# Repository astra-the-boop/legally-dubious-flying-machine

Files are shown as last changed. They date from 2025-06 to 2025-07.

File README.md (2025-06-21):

# la legally dubious flying machine
### Might break several aerospace, telecom, and public order laws but we ball
## Project members: Astra (@astra.celestine on Slack), Ghost (@Minh Anh Ghost on Slack), MD (not in hc), Doggy (not in hc), bingle

## Basically, an RC plane based around just regular commercial airplanes.; ~1m in length; Arduino-controlled; Using LoRa for communication; might add autopilot; DIY Controller + software

---
## Dependencies and libraries or whatever:
-

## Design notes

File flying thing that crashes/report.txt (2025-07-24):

Warning: Width correction constrained.  The width correction value must be in the range of [0.000001 mm; 0.199999 mm] for the current design rules.
Plotted to 'C:\Users\Ghost\Documents\GitHub\legally-dubious-flying-machine\flying thing that crashes\flying thing that crashes-F_Cu.gbr'.
Plotted to 'C:\Users\Ghost\Documents\GitHub\legally-dubious-flying-machine\flying thing that crashes\flying thing that crashes-B_Cu.gbr'.
Plotted to 'C:\Users\Ghost\Documents\GitHub\legally-dubious-flying-machine\flying thing that crashes\flying thing that crashes-F_Paste.gbr'.
Plotted to 'C:\Users\Ghost\Documents\GitHub\legally-dubious-flying-machine\flying thing that crashes\flying thing that crashes-B_Paste.gbr'.
Plotted to 'C:\Users\Ghost\Documents\GitHub\legally-dubious-flying-machine\flying thing that crashes\flying thing that crashes-F_Silkscreen.gbr'.
Plotted to 'C:\Users\Ghost\Documents\GitHub\legally-dubious-flying-machine\flying thing that crashes\flying thing that crashes-B_Silkscreen.gbr'.
Plotted to 'C:\Users\Ghost\Documents\GitHub\legally-dubious-flying-machine\flying thing that crashes\flying thing that crashes-F_Mask.gbr'.
Plotted to 'C:\Users\Ghost\Documents\GitHub\legally-dubious-flying-machine\flying thing that crashes\flying thing that crashes-B_Mask.gbr'.
Plotted to 'C:\Users\Ghost\Documents\GitHub\legally-dubious-flying-machine\flying thing that crashes\flying thing that crashes-Edge_Cuts.gbr'.
Created Gerber job file 'C:\Users\Ghost\Documents\GitHub\legally-dubious-flying-machine\flying thing that crashes\flying thing that crashes-job.gbrjob'.
Info: Done.
Info: Done.

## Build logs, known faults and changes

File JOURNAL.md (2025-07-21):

# Journal :D

## please log whatever you did / are doing, including mistakes here
## https://highway.hackclub.com/advanced/example-journal

## May 8th 2025 - Logger: Ghost
I recieved my 2nd LoRa module and can finally do some testing. I messed around with the LoRa library for aruduino made by Sandeep Mistry.
I tested the Lora module without the antennas and I didn't know that it was a big mistake as it could destroy the radio module and I also found out my LoRa modules are not communicating properly (as long as they are designed for) so i might have fried them.

## May 24th 2025 - Logger: Astra
Today, me and Ghost met up to test the LoRa module I bought the other week since she's unsure if hers works :P
Turns out, both of her LoRa modules got fried (RIP),,, so uh that's great... but at least the "Lo"Ra modules do still work short-range (like a few cm apart) so we can still test that
Outside of that, we also tested the accelerometer / gyro module, and seems to work? i don't understand the readings tho :sob: it's confusing...
We decided to just stop buying new components for now, and work with what we have first, focussing on creating CAD and PCB models first to get the stippends as the entire group is like,,, really broke...




[LoRa video](https://hc-cdn.hel1.your-objectstorage.com/s/v3/142abf9ee1947f46ea742f3a9a95a17131fc7f63_img_3928.mp4)

[gyro testing video](https://hc-cdn.hel1.your-objectstorage.com/s/v3/621003c66919163e77c02e429bbf76a9c26b7368_img_3929.mp4)

## June 6th 2025 - Logger: Astra
Summer finally started + exams are over, so we can finally actually actually start working on this thing... now how the f^^k do i use freecad...

## June 9th 2025 - Logger: Astra
I've been spending the past while trying to figure out how to use FreeCAD to no avail, genuinely cannot figure it out. to be fair, I couldn't figure out how to use the other CAD softwares too, but at least i got a bit further with Onshape so I think I'll be using that :P
Really excited for what's to come :3c

## June 19th 2025 - Logger: Astra
For the past 2 weeks or so I've been tryna figure out CAD modelling. Gave up on using FreeCAD and ended up using Onshape instead. Overall, things seem pretty great :D 
Modelled most of the body and fuselage now, and we'll meet up tomorrow to discuss the wings' measurements so I can model it :D

It took quite a while for me to figure out how to use Onshape, especially figuring out how to use new tools such as the loft tool (which i used for the back of the plane). But now that I figured it out, it's gonna be so much more convenient for future stuff!!!

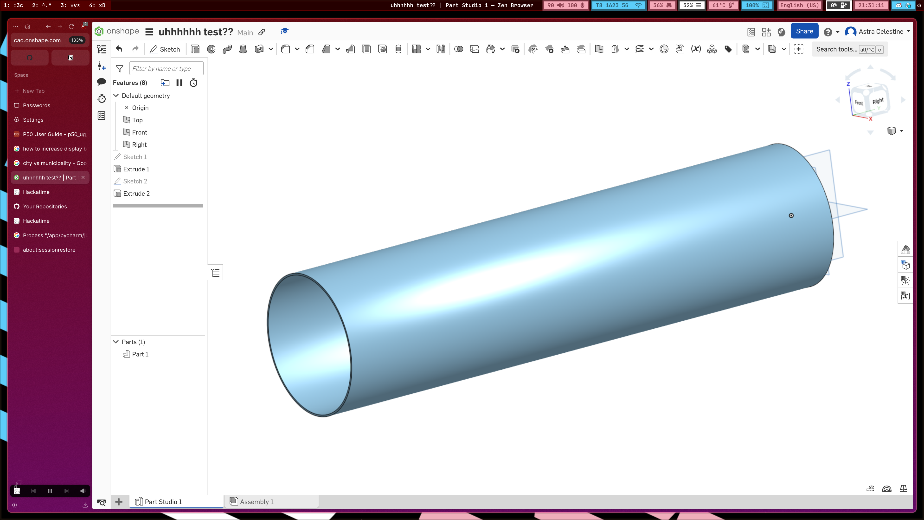
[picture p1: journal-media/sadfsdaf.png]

The first time making something, started with a hollowed out cylinder. We agreed to have the walls be around 5mm thick

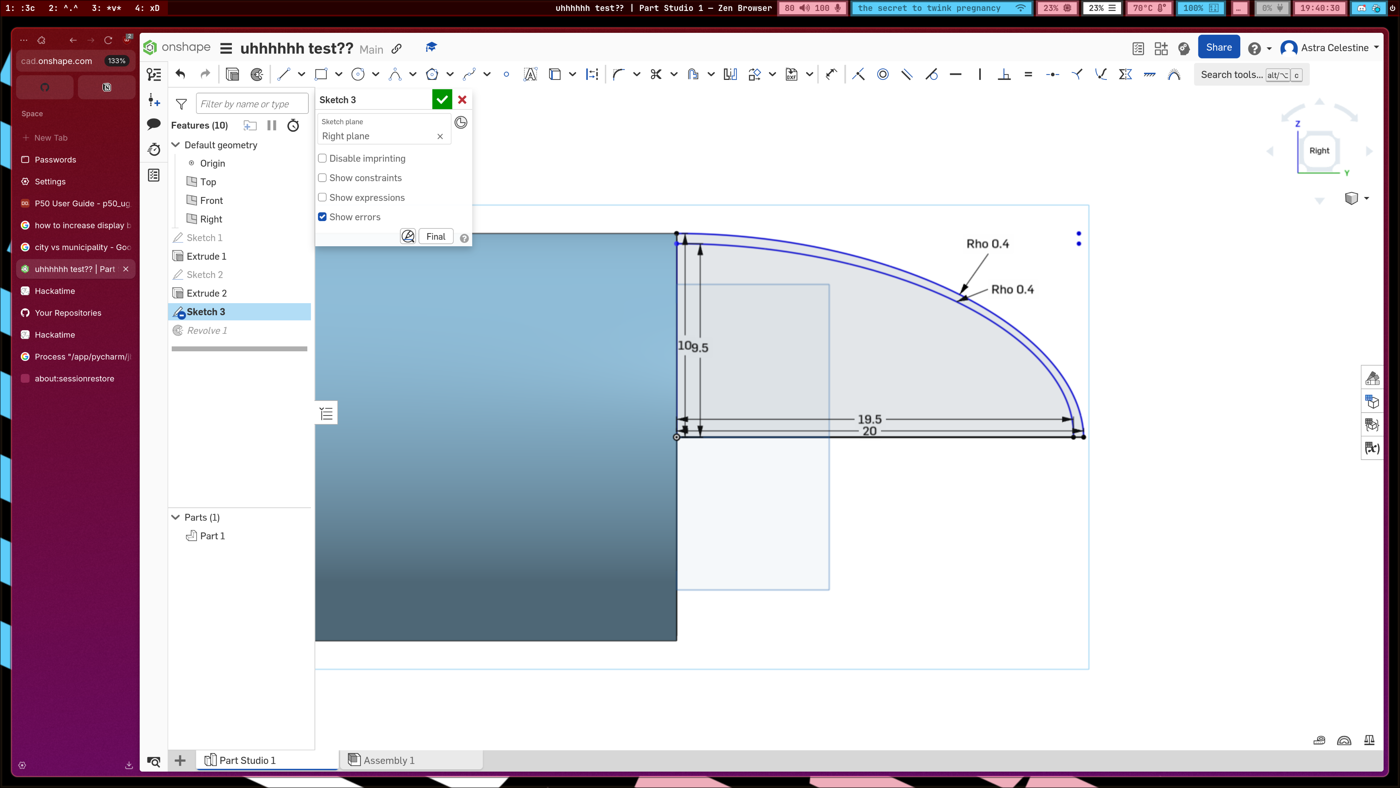
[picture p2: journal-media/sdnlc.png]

Designing nosecone - got feedback from groupmates and ended up changing some things a bit 
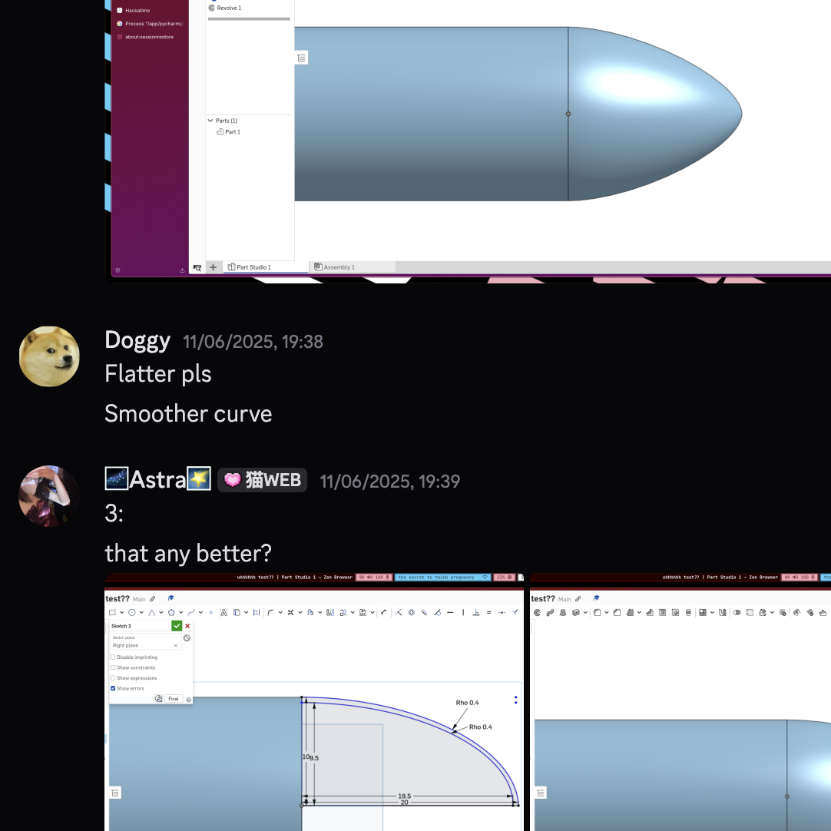
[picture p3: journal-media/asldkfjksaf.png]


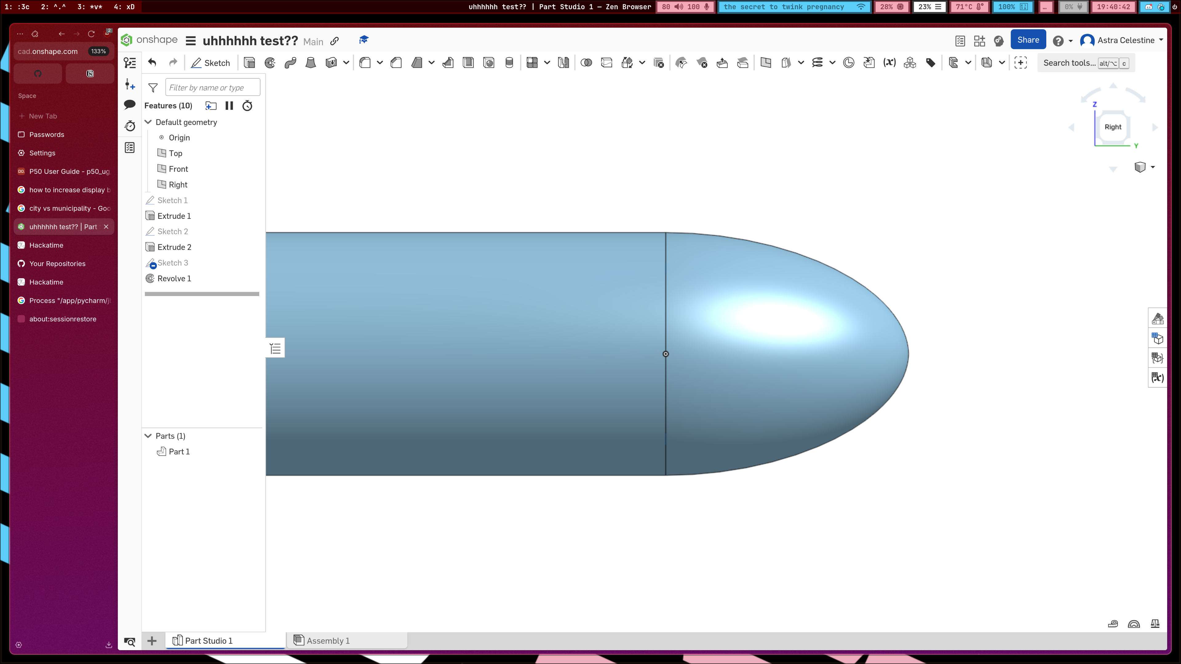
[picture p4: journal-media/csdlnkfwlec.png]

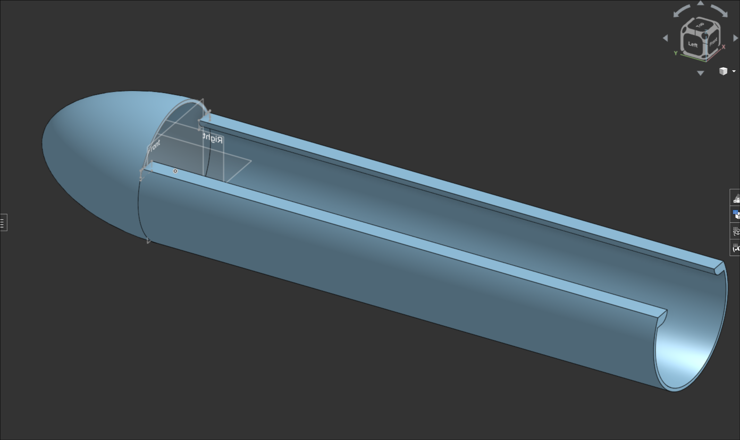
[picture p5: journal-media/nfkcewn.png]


Using the loft tool for the first time to design the tail / back / whatever it's called of the plane. It was quite confusing at first, took me a lot of time to troubleshoot, but at the end of the day, i got it working!!!
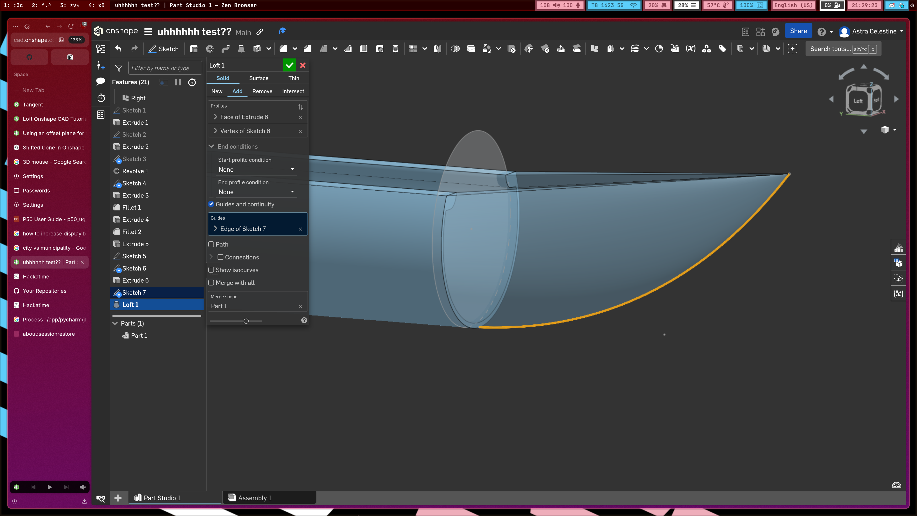
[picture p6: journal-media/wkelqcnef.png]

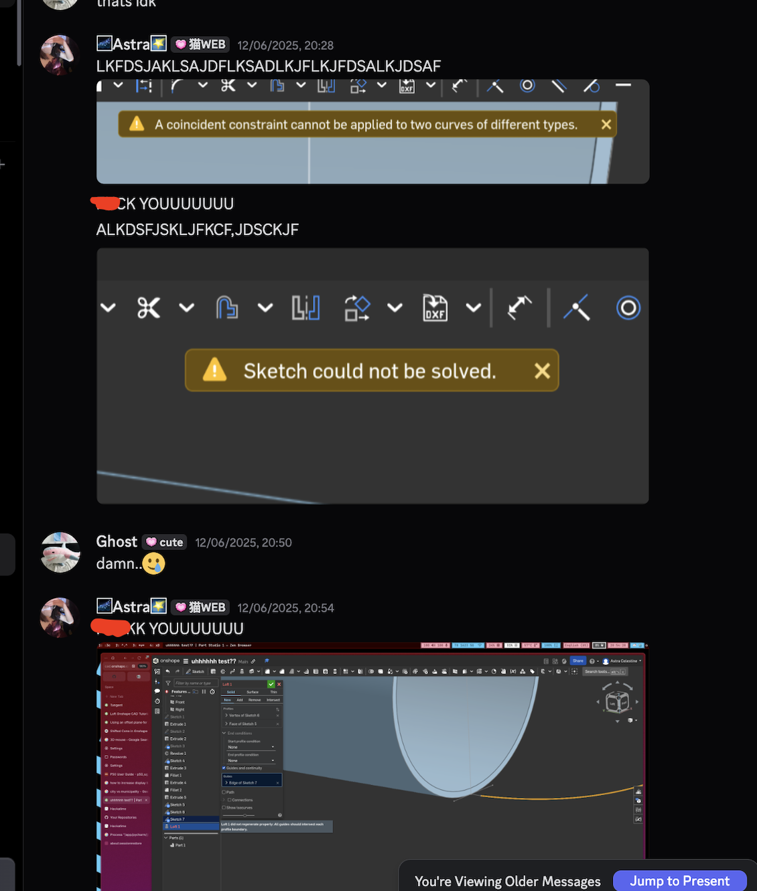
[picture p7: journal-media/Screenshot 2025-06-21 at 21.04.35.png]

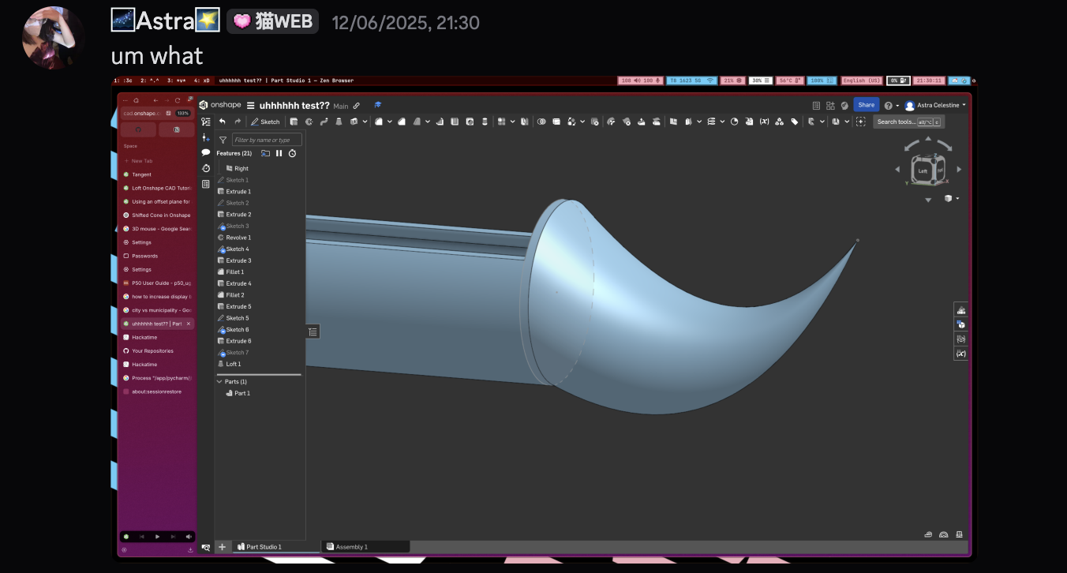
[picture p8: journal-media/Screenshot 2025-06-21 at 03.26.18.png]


Oh and i also forgot to mention, i made it so that the top of the fuselage is removable so it's easy for us to make modifications inside the plane later on without completely disassembling the thing
Here's how the final thing ended up looking
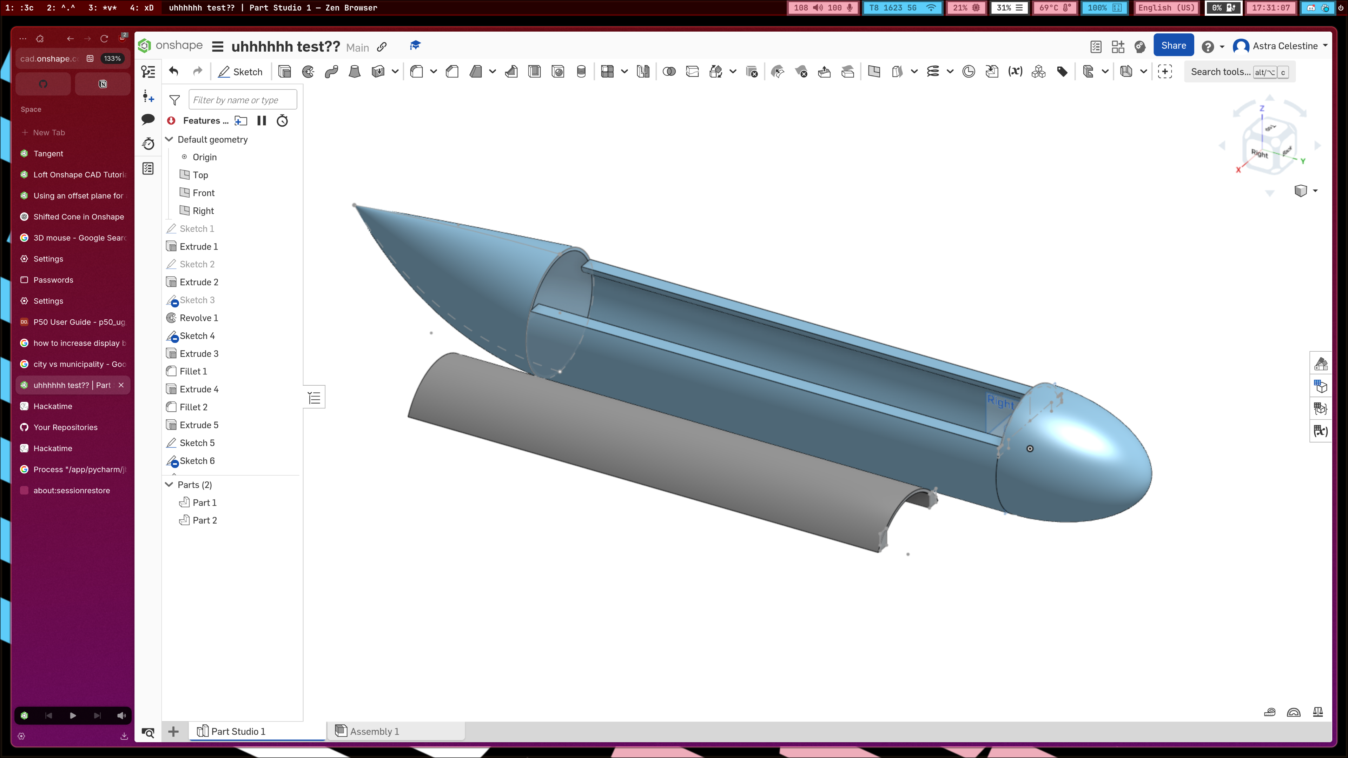
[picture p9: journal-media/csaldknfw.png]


Oh and also added a little holder / base thing for the wing as well
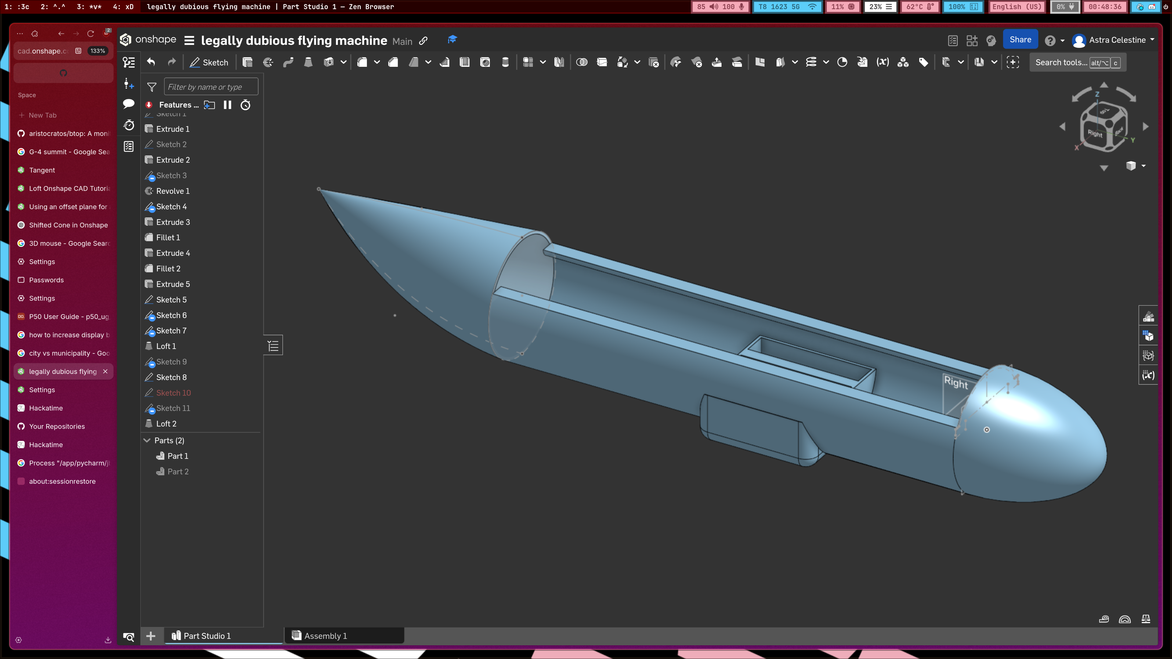
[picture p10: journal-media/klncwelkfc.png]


Gonna be meeting with group tmr so we can discuss wings (i think i alr mentinoed this above but cant find it :P)

## June 20th 2025 - Logger: Astra
Met up with group today!!! generally pretty okay, although less productive than originally planned, we still got all of the planned work done! smh had to bribe the physics nerd to come only for him to slack off the entire time (tbf, his interest is in electrical engineering not aero/fluid-dynamics) :3c
we did a lot of calculations on the estimated weight of the plane once we bought everything (the batteries are SO heavy omg) and it seems pretty likely it'll be able to fly! although we will need a few battery packs (like 4 to 6) for it to fly for any extended period of time though- :(
here are some photos of our meetup!!!






here's some of the stuff that we ended up with :D


also added holes to the thing too, i'll design the 2 wings later :3c
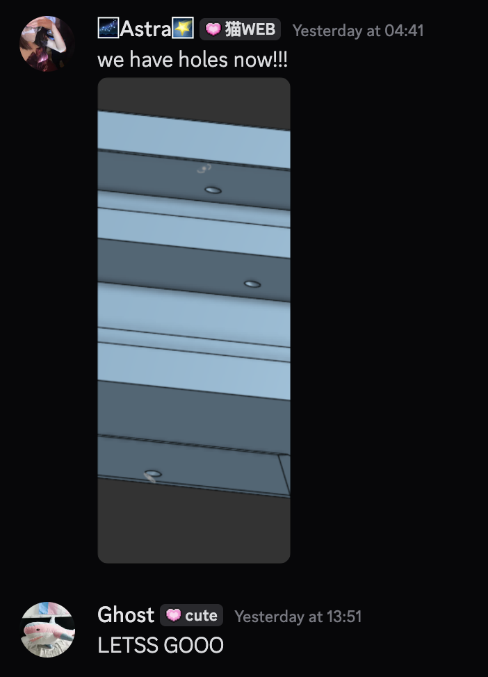
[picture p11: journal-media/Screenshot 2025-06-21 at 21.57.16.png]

took a bit to figure out because it has to be rotated 3º horizontally and 30º vertically :P

## July 1st 2025 - Logger: Ghost
I started to learn how to do pcb, it was quite challanging espescially with all the footprints and I still need to find where all of the components are since im just starting

## July 7th 2024 - Logger: Ghost
I sorta finised the schematic and now I only need to add all the correct footprints and make a board design. The board consists of an Arduino Nano, a pca 9685 pwm LED controller for the servos and 2 motors, 1 buck boost converter for stability and an ams1117 for the LORA modules.

## July 18th 2024 - Logger: Astra
so uh yeah i did finish the wings technically a few weeks ago, BUT i realised that 30º might be a bit too big, so i ended up having to restart the entire damned thing, making it 25º... but yeah just last week i pretty much finished the main form of the wing for the most part, so i spent like a whole night or so remodelling everything. the math was really annoying, really tested my 3D vector and sohcahtoa shit (god save me i hate maths) but yeah, i did this once before so it's not _that_ big of an issue :3c

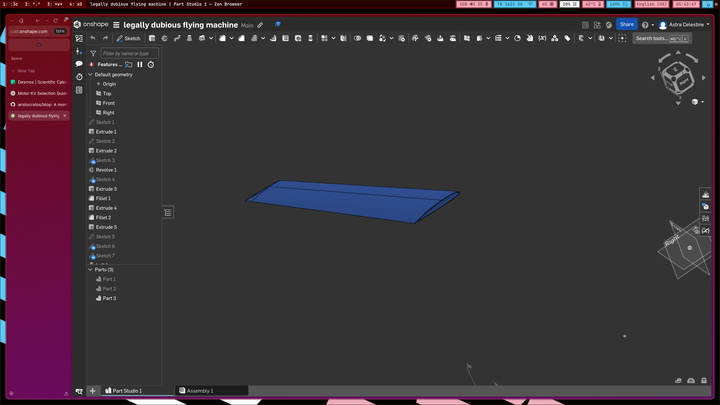
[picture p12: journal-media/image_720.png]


it honestly took me way too long to make the curvy thing at the end :sob: kasdlj,cf,dc,f

anyway, gonna spend a bit modelling the uHH thing.. uh the motor-holder on the wings as well as the things for uhHHHHHHHHHHHHHHH the .... what's it called again.. servos yes servos

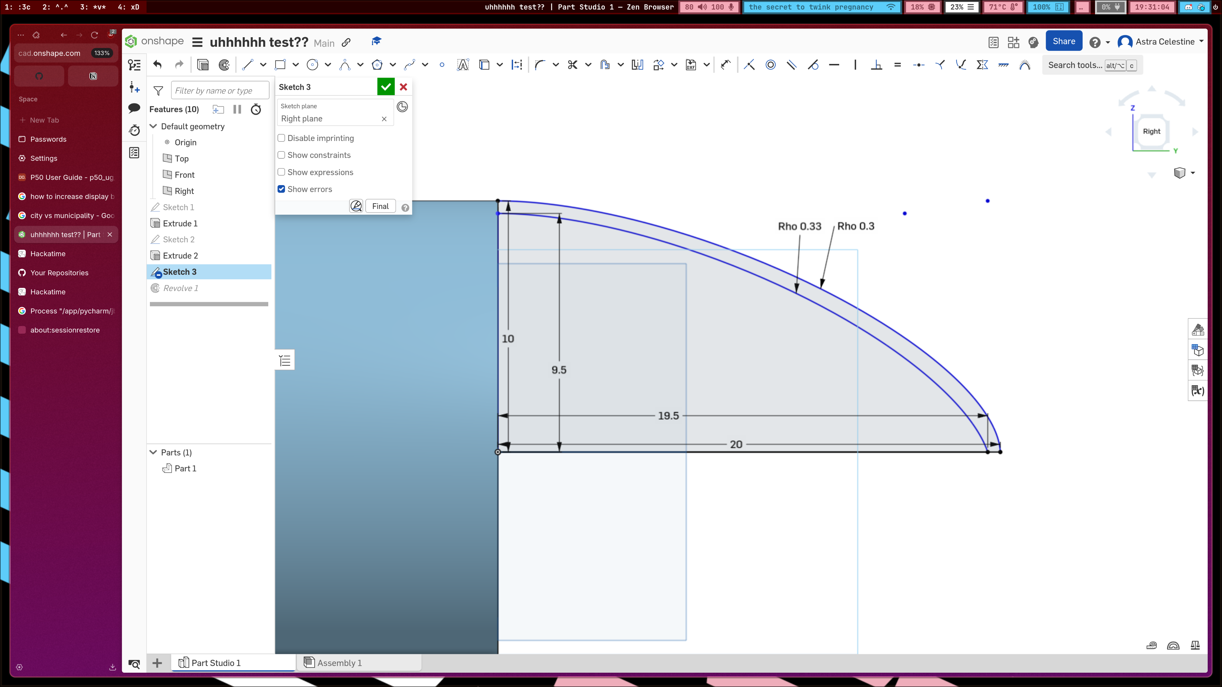
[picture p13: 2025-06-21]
journal-media/slkdafj.png

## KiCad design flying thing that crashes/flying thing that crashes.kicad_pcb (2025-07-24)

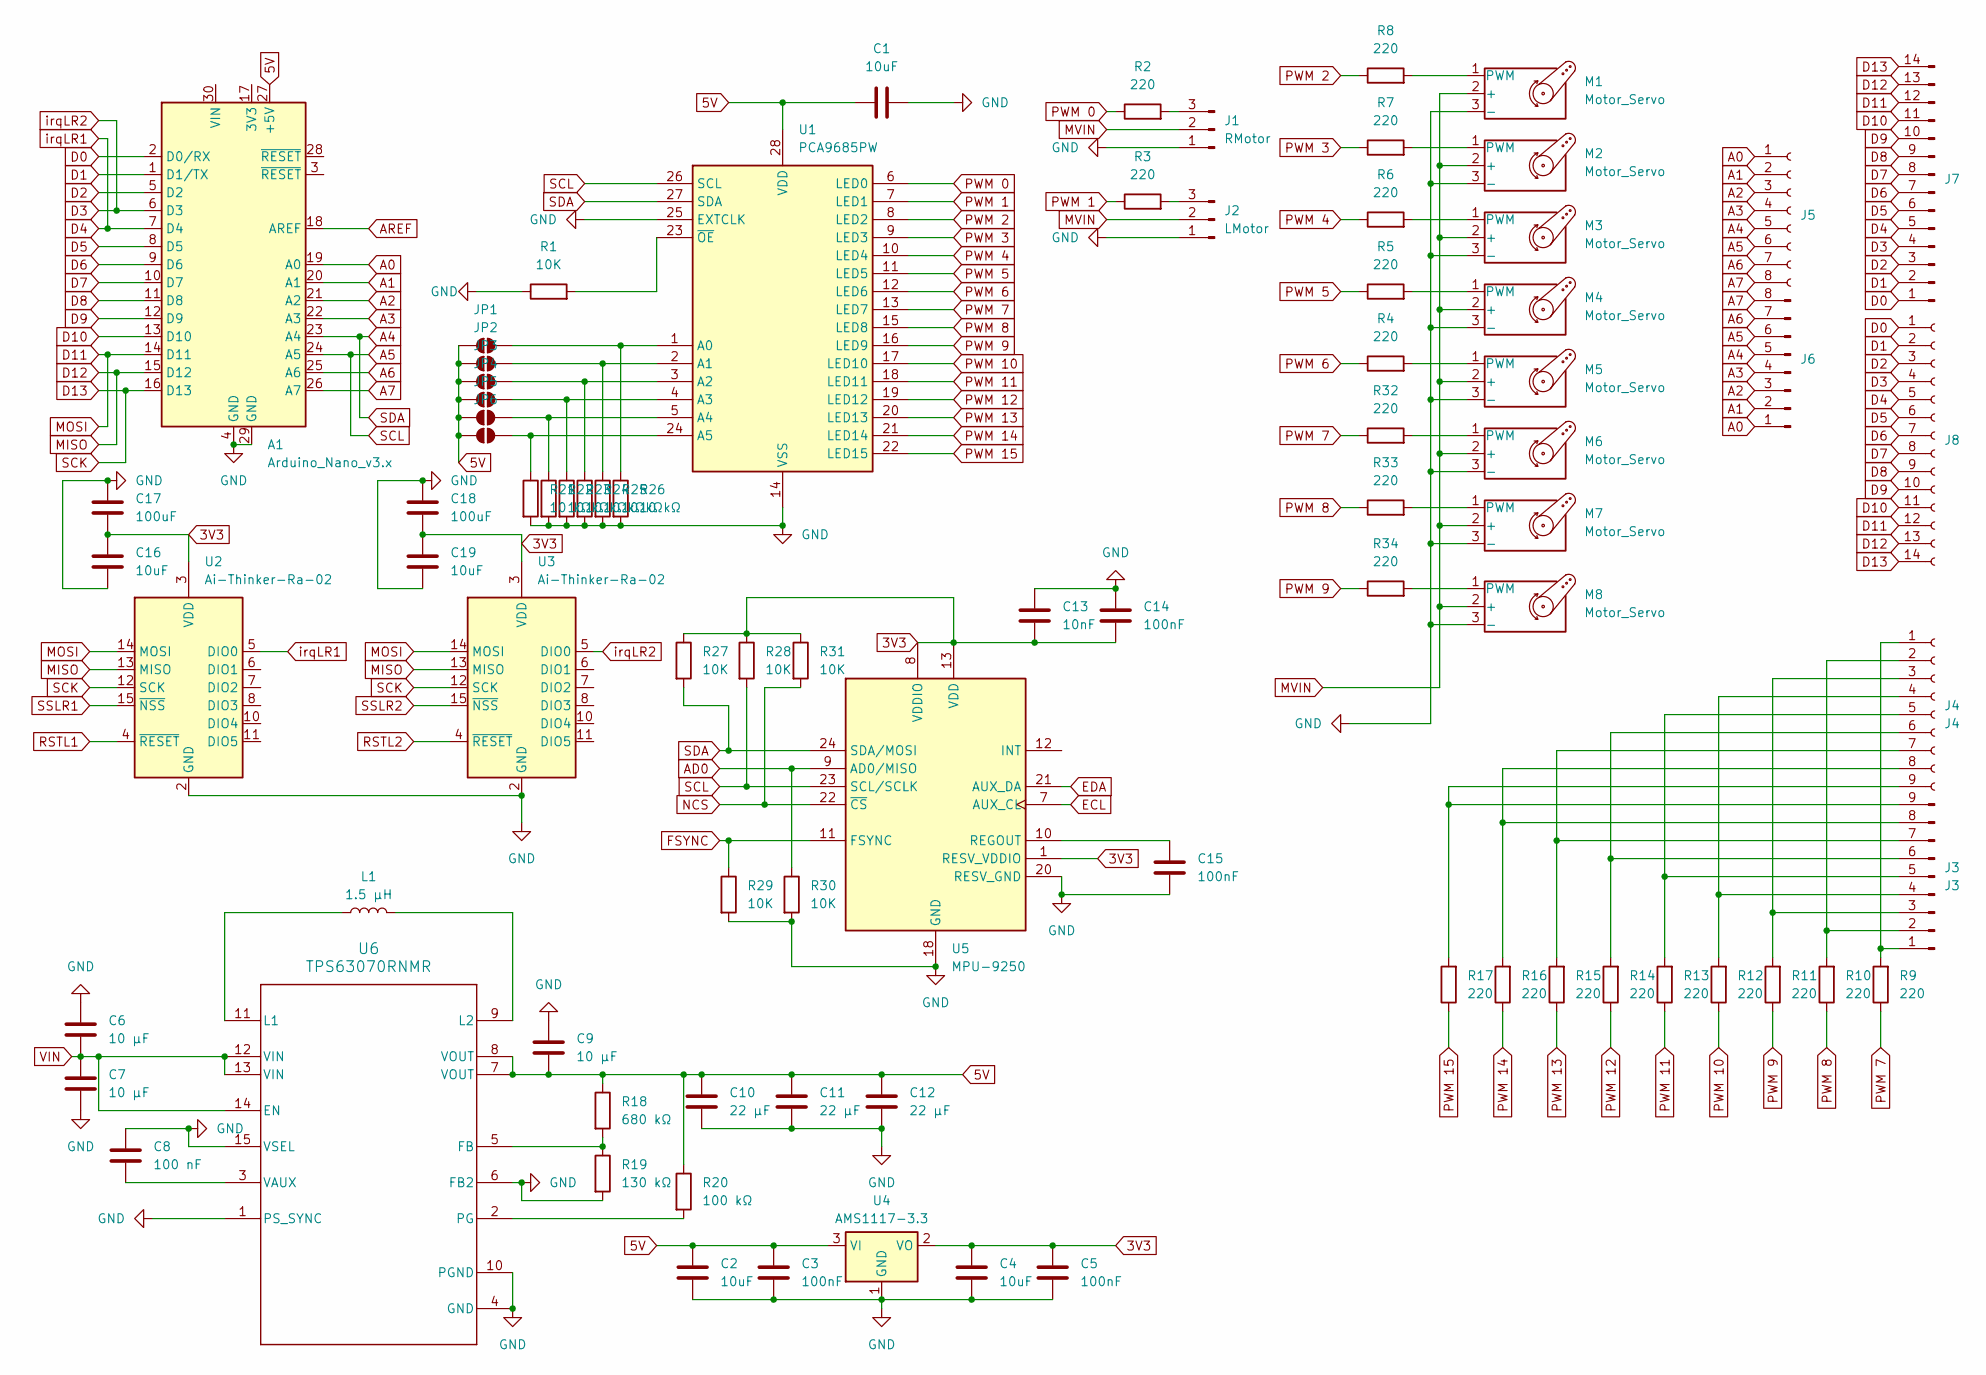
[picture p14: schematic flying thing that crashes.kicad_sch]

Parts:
A1: Arduino_Nano_v3.x; Arduino_Nano
C1, C2, C4: 10uF; C_0603_1608Metric
C3, C5: 100nF; C_1206_3216Metric
C6, C7: 10 µF; C_0805_2012Metric
C8: 100 nF; C_1206_3216Metric
C9: 10 µF; C_0603_1608Metric
C10, C11, C12: 22 µF; C_0805_2012Metric
C13: 10nF; C_0805_2012Metric
C14, C15: 100nF; C_0805_2012Metric
C16, C19: 10uF; C_0805_2012Metric
C17, C18: 100uF; C_0805_2012Metric
J1: RMotor; PinHeader_1x03_P2.00mm_Vertical
J2: LMotor; PinHeader_1x03_P2.00mm_Vertical
J3: J3; PinHeader_1x09_P2.00mm_Vertical
J4: J4; PinSocket_1x09_P2.00mm_Vertical
J5: PinSocket_1x08_P2.00mm_Vertical
J6: PinHeader_1x08_P2.00mm_Vertical
J7: PinHeader_1x14_P2.00mm_Vertical
J8: PinSocket_1x14_P2.00mm_Vertical
JP1, JP2, JP3, JP4, JP5, JP6: SolderJumper-2_P1.3mm_Open_RoundedPad1.0x1.5mm
L1: 1.5 µH; IND_XFL4020-152MEC
M1, M2, M3, M4, M5, M6, M7, M8: Motor_Servo; PinHeader_1x03_P2.00mm_Vertical
R1: 10K; R_1206_3216Metric
R2, R3, R4, R5, R6, R7, R8, R9, R10, R11, R12, R13, R14, R15, R16, R17, R32, R33, R34: 220; R_1206_3216Metric
R18: 680 kΩ; R_0805_2012Metric
R19: 130 kΩ; R_0805_2012Metric
R20: 100 kΩ; R_0805_2012Metric
R21, R22, R23, R24, R25, R26: 10 kΩ; R_0805_2012Metric
R27, R28, R29, R30, R31: 10K; R_0805_2012Metric
U1: PCA9685PW; TSSOP-28_4.4x9.7mm_P0.65mm
U2, U3: Ai-Thinker-Ra-02; Ai-Thinker-Ra-01-LoRa
U4: AMS1117-3.3; SOT-223-3_TabPin2
U5: MPU-9250; InvenSense_QFN-24_3x3mm_P0.4mm
U6: TPS63070RNMR; RNM0015A

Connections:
3V3: C4.1, C5.1, C13.2, C14.2, C16.1, C17.2, C18.2, C19.1, R27.1, R28.1, R31.1, U2.3 (VDD), U3.3 (VDD), U4.2 (VO), U5.1 (RESV_VDDIO), U5.8 (VDDIO), U5.13 (VDD)
5V: A1.27 (+5V), C1.1, C2.1, C3.1, C9.2, C10.1, C11.1, C12.1, JP1.1 (A), JP2.1 (A), JP3.1 (A), JP4.1 (A), JP5.1 (A), JP6.1 (A), R18.1, R20.1, U1.28 (VDD), U4.3 (VI), U6.7 (VOUT), U6.8 (VOUT)
A0: A1.19 (A0), J5.1, J6.1
A1: A1.20 (A1), J5.2, J6.2
A2: A1.21 (A2), J5.3, J6.3
A3: A1.22 (A3), J5.4, J6.4
A4: A1.23 (A4), J5.5, J6.5, R27.2, U1.27 (SDA), U5.24 (SDA/MOSI)
A5: A1.24 (A5), J5.6, J6.6, R28.2, U1.26 (SCL), U5.23 (SCL/SCLK)
A6: A1.25 (A6), J5.7, J6.7
A7: A1.26 (A7), J5.8, J6.8
AD0: R30.1, U5.9 (AD0/MISO)
AREF: A1.18 (AREF)
D0: A1.2 (D0/RX), J7.1, J8.1
D1: A1.1 (D1/TX), J7.2, J8.2
D2: A1.5 (D2), J7.3, J8.3
D3: A1.6 (D3), J7.4, J8.4, U3.5 (DIO0)
D4: A1.7 (D4), J7.5, J8.5, U2.5 (DIO0)
D5: A1.8 (D5), J7.6, J8.6
D6: A1.9 (D6), J7.7, J8.7
D7: A1.10 (D7), J7.8, J8.8
D8: A1.11 (D8), J7.9, J8.9
D9: A1.12 (D9), J7.10, J8.10
D10: A1.13 (D10), J7.11, J8.11
D11: A1.14 (D11), J7.12, J8.12, U2.14 (MOSI), U3.14 (MOSI)
D12: A1.15 (D12), J7.13, J8.13, U2.13 (MISO), U3.13 (MISO)
D13: A1.16 (D13), J7.14, J8.14, U2.12 (SCK), U3.12 (SCK)
ECL: U5.7 (AUX_CL)
EDA: U5.21 (AUX_DA)
FSYNC: R29.1, U5.11 (FSYNC)
GND: A1.4 (GND), A1.29 (GND), C1.2, C2.2, C3.2, C4.2, C5.2, C6.1, C7.2, C8.1, C9.1, C10.2, C11.2, C12.2, C13.1, C14.1, C15.2, C16.2, C17.1, C18.1, C19.2, J1.1, J2.1, M1.3 (-), M2.3 (-), M3.3 (-), M4.3 (-), M5.3 (-), M6.3 (-), M7.3 (-), M8.3 (-), R1.1, R19.2, R21.2, R22.2, R23.2, R24.2, R25.2, R26.2, R29.2, R30.2, U1.14 (VSS), U1.25 (EXTCLK), U2.1 (GND), U2.2 (GND), U2.9 (GND), U2.16 (GND), U3.1 (GND), U3.2 (GND), U3.9 (GND), U3.16 (GND), U4.1 (GND), U5.18 (GND), U5.20 (RESV_GND), U6.1 (PS_SYNC), U6.4 (GND), U6.6 (FB2), U6.10 (PGND), U6.15 (VSEL)
MVIN: J1.2, J2.2, M1.2 (+), M2.2 (+), M3.2 (+), M4.2 (+), M5.2 (+), M6.2 (+), M7.2 (+), M8.2 (+)
NCS: R31.2, U5.22 (~CS)
unnamed: J1.3, R2.2
unnamed: J2.3, R3.2
unnamed: J3.1, J4.1, R9.2
unnamed: J3.2, J4.2, R10.2
unnamed: J3.3, J4.3, R11.2
unnamed: J3.4, J4.4, R12.2
unnamed: J3.5, J4.5, R13.2
unnamed: J3.6, J4.6, R14.2
unnamed: J3.7, J4.7, R15.2
unnamed: J3.8, J4.8, R16.2
unnamed: J3.9, J4.9, R17.2
unnamed: JP1.2 (B), R26.1, U1.1 (A0)
unnamed: JP2.2 (B), R25.1, U1.2 (A1)
unnamed: JP3.2 (B), R24.1, U1.3 (A2)
unnamed: JP4.2 (B), R23.1, U1.4 (A3)
unnamed: JP5.2 (B), R22.1, U1.5 (A4)
unnamed: JP6.2 (B), R21.1, U1.24 (A5)
unnamed: M1.1 (PWM), R8.2
unnamed: M2.1 (PWM), R7.2
unnamed: M3.1 (PWM), R6.2
unnamed: M4.1 (PWM), R5.2
unnamed: M5.1 (PWM), R4.2
unnamed: M6.1 (PWM), R32.2
unnamed: M7.1 (PWM), R33.2
unnamed: M8.1 (PWM), R34.2
unnamed: R1.2, U1.23 (~OE)
unnamed: C15.1, U5.10 (REGOUT)
unnamed: R18.2, R19.1, U6.5 (FB)
unnamed: L1.1, U6.11 (L1)
unnamed: L1.2, U6.9 (L2)
unnamed: R20.2, U6.2 (PG)
unnamed: C8.2, U6.3 (VAUX)
PWM 0: R2.1, U1.6 (LED0)
PWM 1: R3.1, U1.7 (LED1)
PWM 2: R8.1, U1.8 (LED2)
PWM 3: R7.1, U1.9 (LED3)
PWM 4: R6.1, U1.10 (LED4)
PWM 5: R5.1, U1.11 (LED5)
PWM 6: R4.1, U1.12 (LED6)
PWM 7: R9.1, R32.1, U1.13 (LED7)
PWM 8: R10.1, R33.1, U1.15 (LED8)
PWM 9: R11.1, R34.1, U1.16 (LED9)
PWM 10: R12.1, U1.17 (LED10)
PWM 11: R13.1, U1.18 (LED11)
PWM 12: R14.1, U1.19 (LED12)
PWM 13: R15.1, U1.20 (LED13)
PWM 14: R16.1, U1.21 (LED14)
PWM 15: R17.1, U1.22 (LED15)
RSTL1: U2.4 (~RESET)
RSTL2: U3.4 (~RESET)
SSLR1: U2.15 (~NSS)
SSLR2: U3.15 (~NSS)
VIN: C6.2, C7.1, U6.12 (VIN), U6.13 (VIN), U6.14 (EN)

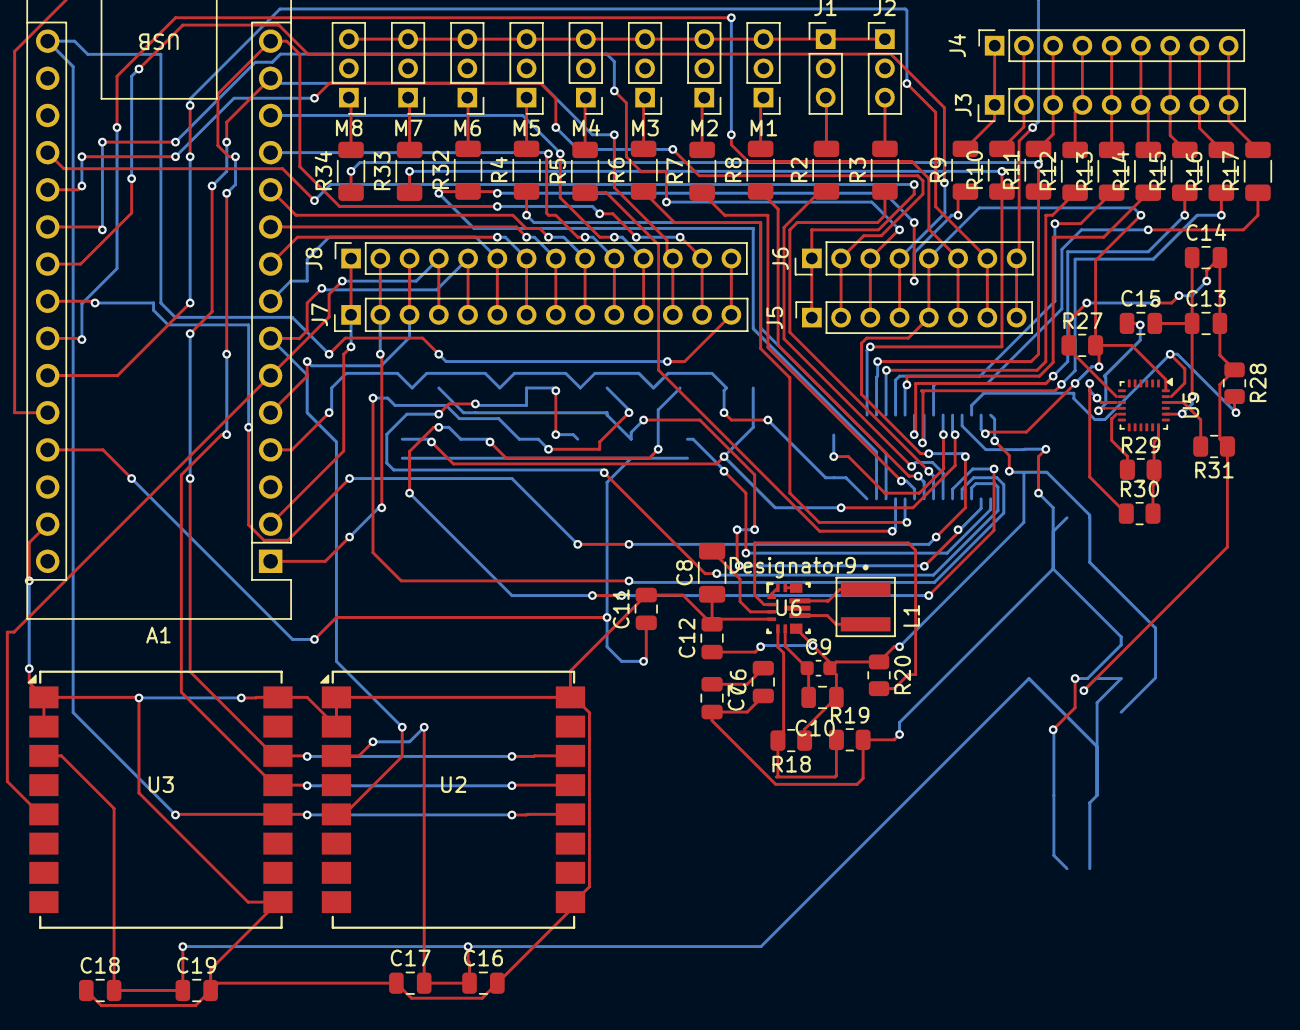
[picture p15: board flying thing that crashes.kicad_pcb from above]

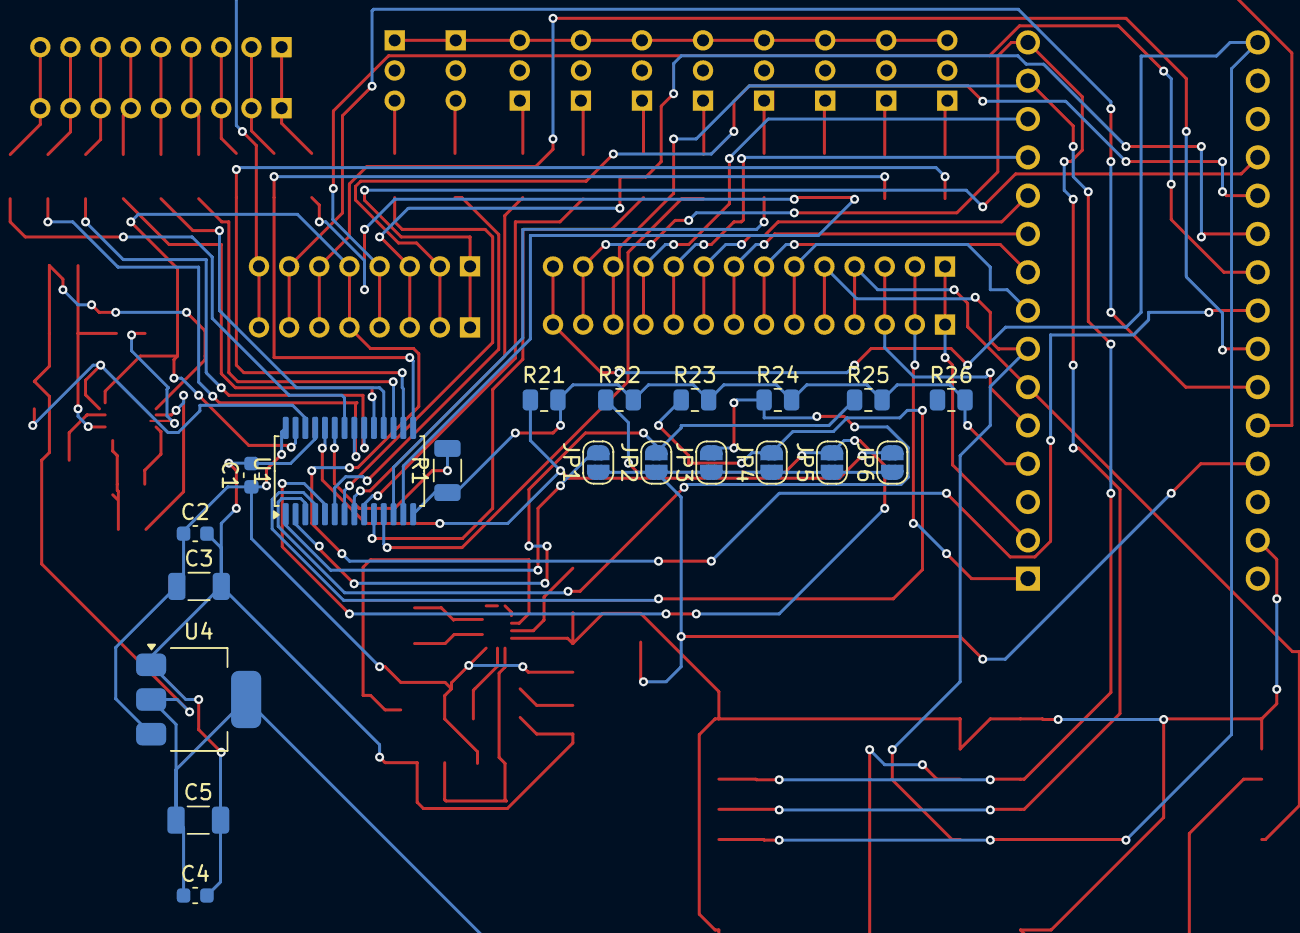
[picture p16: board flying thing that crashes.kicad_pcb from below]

Board: 2 copper layers, 83 parts (20 on the bottom side), 78 nets.

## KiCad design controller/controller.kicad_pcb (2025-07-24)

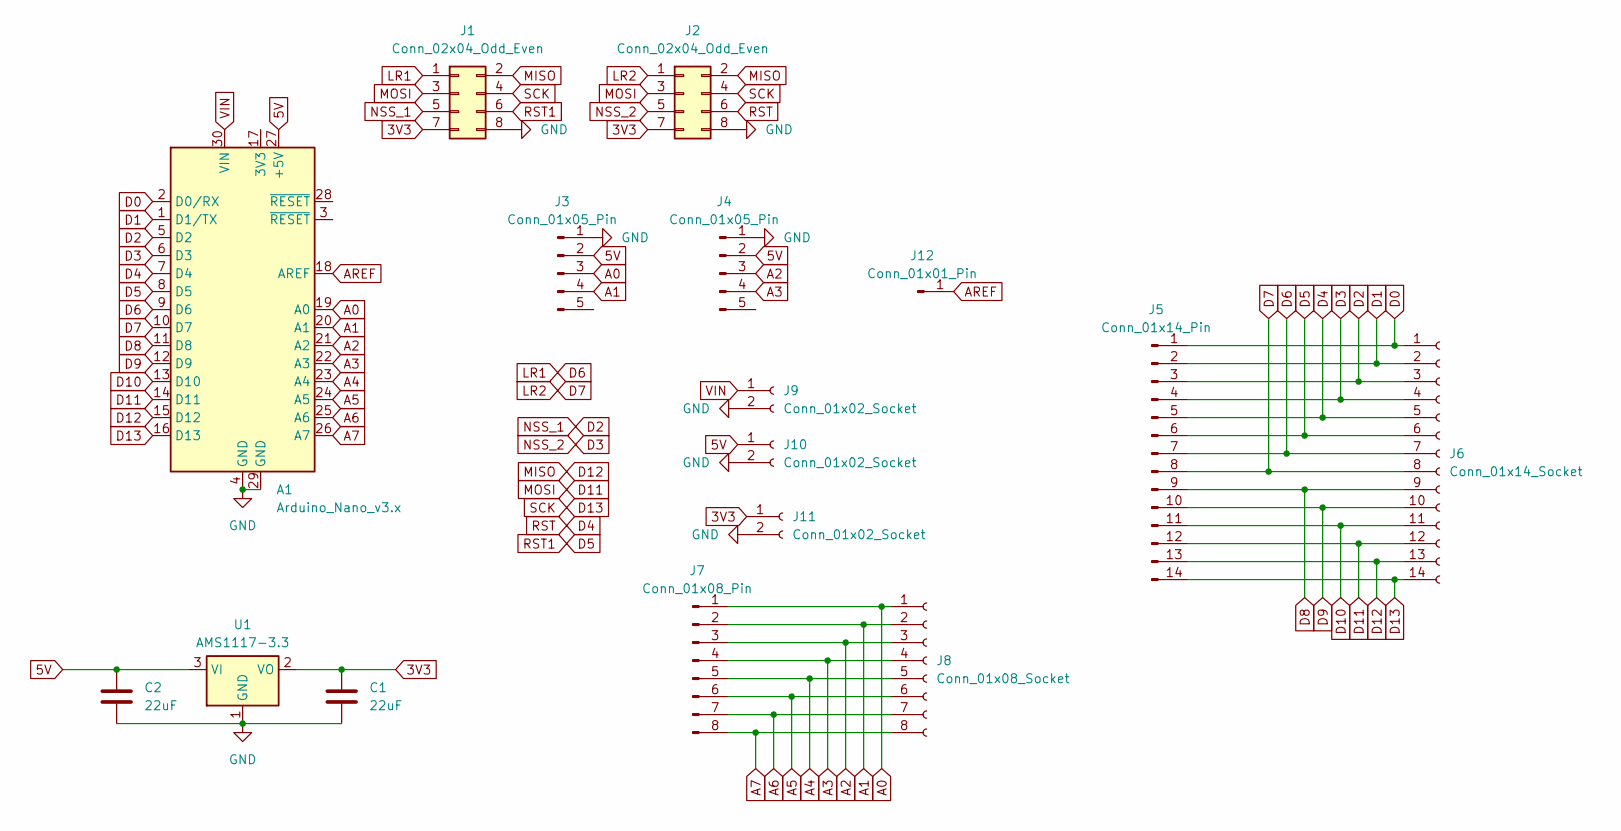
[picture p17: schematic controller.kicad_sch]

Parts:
A1: Arduino_Nano_v3.x; Arduino_Nano
C1, C2: 22uF; C_0603_1608Metric
J1, J2: Conn_02x04_Odd_Even; PinSocket_2x04_P2.54mm_Vertical
J3, J4: Conn_01x05_Pin; PinHeader_1x05_P2.54mm_Vertical
J5: Conn_01x14_Pin; PinHeader_1x14_P2.54mm_Vertical
J6: Conn_01x14_Socket; PinSocket_1x14_P2.54mm_Vertical
J7: Conn_01x08_Pin; PinHeader_1x08_P2.54mm_Vertical
J8: Conn_01x08_Socket; PinSocket_1x08_P2.54mm_Vertical
J9, J10, J11: Conn_01x02_Socket; PinHeader_1x02_P2.54mm_Vertical
J12: Conn_01x01_Pin; PinHeader_1x01_P2.54mm_Vertical
U1: AMS1117-3.3; SOT-223-3_TabPin2

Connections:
3V3: C1.1, J1.7, J2.7, J11.1, U1.2 (VO)
5V: A1.27 (+5V), C2.1, J3.2, J4.2, J10.1, U1.3 (VI)
A0: A1.19 (A0), J3.3, J7.1, J8.1
A1: A1.20 (A1), J3.4, J7.2, J8.2
A2: A1.21 (A2), J4.3, J7.3, J8.3
A3: A1.22 (A3), J4.4, J7.4, J8.4
A4: A1.23 (A4), J7.5, J8.5
A5: A1.24 (A5), J7.6, J8.6
A6: A1.25 (A6), J7.7, J8.7
A7: A1.26 (A7), J7.8, J8.8
AREF: A1.18 (AREF), J12.1
D0: A1.2 (D0/RX), J5.1, J6.1
D1: A1.1 (D1/TX), J5.2, J6.2
D2: A1.5 (D2), J1.5, J5.3, J6.3
D3: A1.6 (D3), J2.5, J5.4, J6.4
D4: A1.7 (D4), J2.6, J5.5, J6.5
D5: A1.8 (D5), J1.6, J5.6, J6.6
D6: A1.9 (D6), J1.1, J5.7, J6.7
D7: A1.10 (D7), J2.1, J5.8, J6.8
D8: A1.11 (D8), J5.9, J6.9
D9: A1.12 (D9), J5.10, J6.10
D10: A1.13 (D10), J5.11, J6.11
D11: A1.14 (D11), J1.3, J2.3, J5.12, J6.12
D12: A1.15 (D12), J1.2, J2.2, J5.13, J6.13
D13: A1.16 (D13), J1.4, J2.4, J5.14, J6.14
GND: A1.4 (GND), A1.29 (GND), C1.2, C2.2, J1.8, J2.8, J3.1, J4.1, J9.2, J10.2, J11.2, U1.1 (GND)
VIN: A1.30 (VIN), J9.1

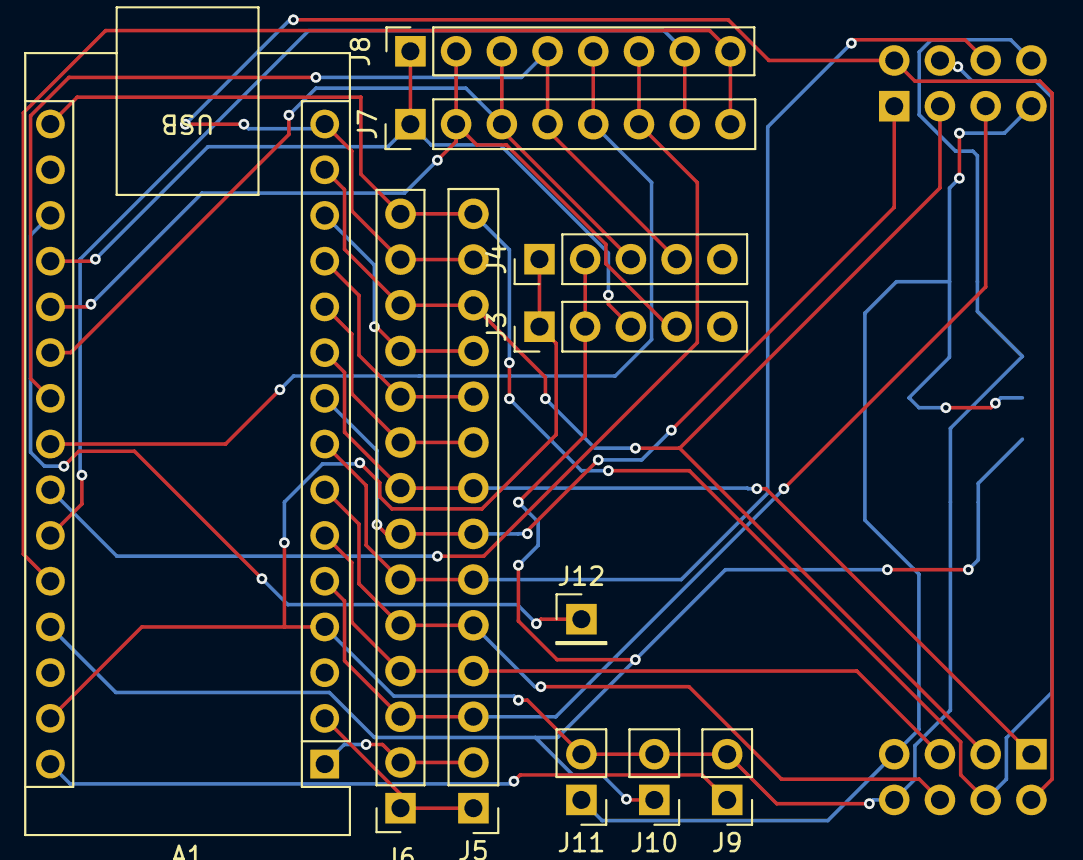
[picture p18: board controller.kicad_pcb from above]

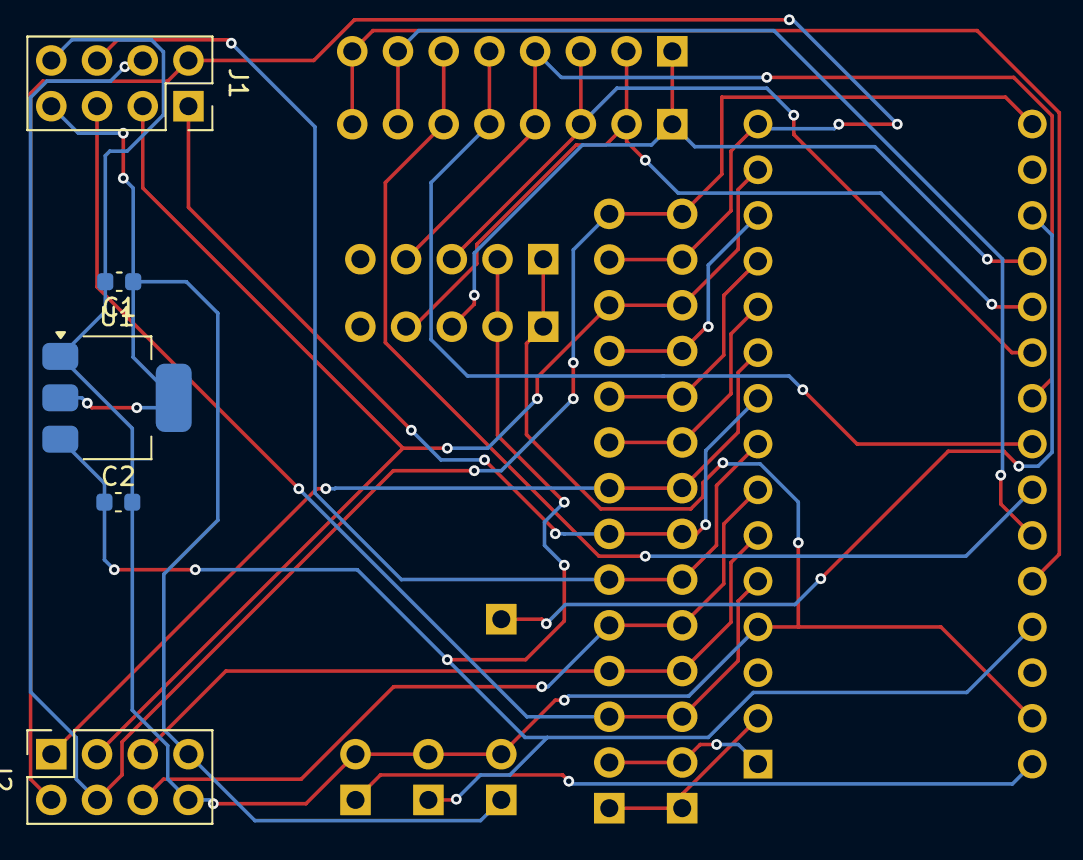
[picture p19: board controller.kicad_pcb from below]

Board: 2 copper layers, 16 parts (5 on the bottom side), 27 nets.

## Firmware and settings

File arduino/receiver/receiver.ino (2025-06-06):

#include <SPI.h>
#include <LoRa.h>

void setup() {
  Serial.begin(9600);
  while (!Serial);
  LoRa.setPins(7, 6, 8);// set CS, reset, IRQ pin

  Serial.println("LoRa Receiver");

  if (!LoRa.begin(915E6)) {
    Serial.println("Starting LoRa failed!");
    while (1);
  }
}

void loop() {
  // try to parse packet
  int packetSize = LoRa.parsePacket();
  if (packetSize) {
    // received a packet
    Serial.print("Received packet '");

    // read packet
    while (LoRa.available()) {
      Serial.print((char)LoRa.read());
    }

    // print RSSI of packet
    Serial.print("' with RSSI ");
    Serial.println(LoRa.packetRssi());
  }
}

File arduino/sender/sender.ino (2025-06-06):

#include <SPI.h>
#include <LoRa.h>

int counter = 0;

void setup() {
  Serial.begin(9600);
  while (!Serial);
  LoRa.setPins(7, 6, 8);// NSS, reset, DIO0

  Serial.println("LoRa Sender");

  if (!LoRa.begin(915E6)) {
    Serial.println("Starting LoRa failed!");
    while (1);
  }
}

void loop() {
  Serial.print("Sending packet: ");
  Serial.println(counter);

  // send packet
  LoRa.beginPacket();
  LoRa.print("hello ");
  LoRa.print(counter);
  LoRa.endPacket();

  counter++;

  delay(500);
}

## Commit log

2025-05-25 Track .MOV files with Git LFS
2025-07-18 Flight controller kicad design
    Flight controller plan (schematic is finished, still working on the final pcb design
    [flying thing that crashes.kicad_pcb, flying thing that crashes.kicad_sch]
2025-07-21 update(almost done)
    [flying thing that crashes.kicad_pcb, flying thing that crashes.kicad_sch]
2025-07-22 final draft
    [flying thing that crashes.kicad_pcb]
2025-07-22 tweeks to final draft(cleenup)
    [flying thing that crashes.kicad_pcb]
